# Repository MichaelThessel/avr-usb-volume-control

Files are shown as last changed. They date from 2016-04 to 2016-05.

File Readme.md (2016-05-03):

### USB Volume Control ###

Firmware for USB volume control board

This is project utilizes the [VUSB library](https://github.com/MichaelThessel/avr-usb-volume-control) by Objective Development. A detailed description of the project can be found [here](http://michaelthessel.com/usb-volume-control/). The KiCad design files are located in the PCB folder.

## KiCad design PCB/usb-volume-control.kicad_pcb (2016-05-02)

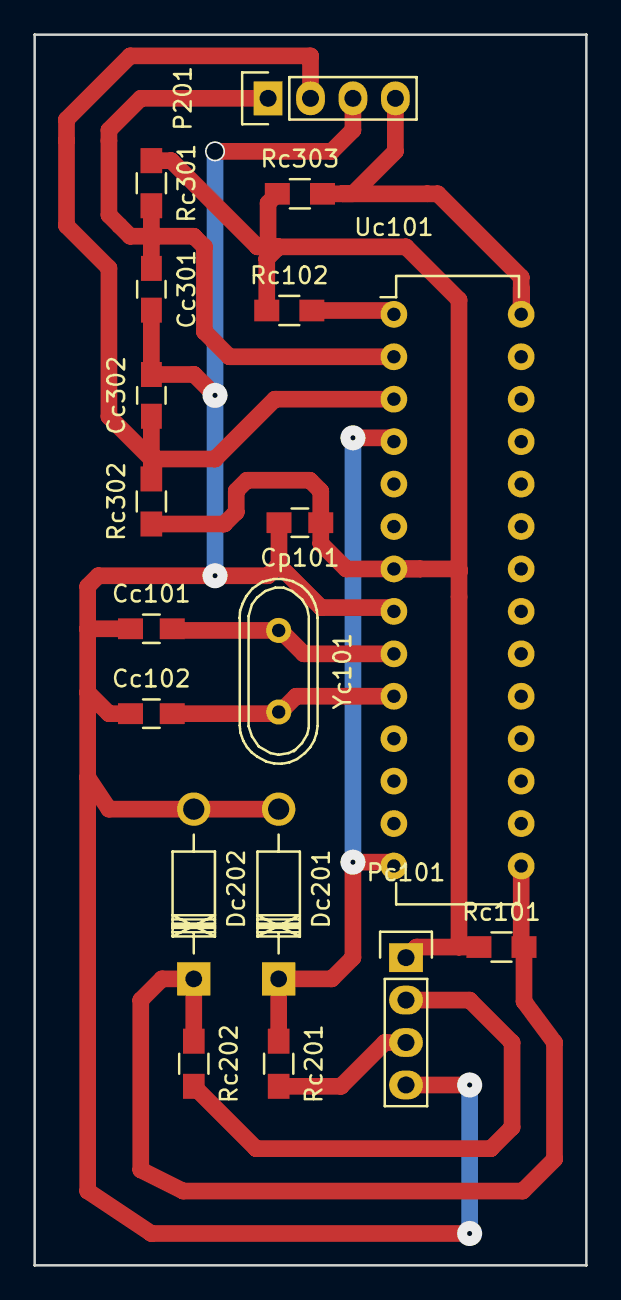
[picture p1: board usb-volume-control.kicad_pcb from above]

Board: 2 copper layers, 33.0 x 73.7 mm, 18 parts (0 on the bottom side), 12 nets.

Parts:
Cc101, Cc102: 22pF; C_0805_HandSoldering
Cc301, Cc302: 1uF; C_0805_HandSoldering
Cp101: 10uF; C_0805_HandSoldering
Dc201, Dc202: 3V6; Diode_DO-41_SOD81_Horizontal_RM10
P201: ROT ENC; Pin_Header_Straight_1x04
Pc101: USB; Pin_Header_Straight_1x04
Rc101, Rc102, Rc301, Rc302, Rc303: 2k; R_0805_HandSoldering
Rc201, Rc202: 47R; R_0805_HandSoldering
Uc101: ATMEGA328P-P; DIP-28_W7.62mm
Yc101: Crystal; Crystal_HC49-U_Vertical

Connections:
GND: Cc101.1, Cc102.1, Cc301.2, Cc302.2, Cp101.2, Dc201.2, Dc202.2, P201.3, Pc101.4, Uc101.8
unnamed: Cc101.2, Uc101.9, Yc101.1
unnamed: Cc102.2, Uc101.10, Yc101.2
unnamed: Cc301.1, P201.1, Rc301.2, Uc101.2
unnamed: Cc302.1, P201.2, Rc302.2, Uc101.3
unnamed: Dc201.1, Rc201.1, Uc101.4, Uc101.14
unnamed: Dc202.1, Rc101.2, Rc202.1, Uc101.15
unnamed: P201.4, Rc303.2, Uc101.28
unnamed: Pc101.2, Rc202.2
unnamed: Pc101.3, Rc201.2
unnamed: Rc102.2, Uc101.1
VCC: Cp101.1, Pc101.1, Rc101.1, Rc102.1, Rc301.1, Rc302.1, Rc303.1, Uc101.7

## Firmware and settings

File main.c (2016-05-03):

#include <avr/io.h>
#include <avr/wdt.h>
#include <avr/interrupt.h>
#include <util/delay.h>
#include <avr/pgmspace.h>

#include "usbdrv/usbdrv.h"

#define STATUS_IDLE 0
#define STATUS_STOP 1
#define STATUS_UP 2
#define STATUS_DOWN 3
#define STATUS_MUTE 4

#define REPID_MMKEY 3

volatile int status = 0;

static uint8_t reportBuffer[3];
static uchar idleRate;

volatile short debounceActive = 0;

const PROGMEM char usbHidReportDescriptor[USB_CFG_HID_REPORT_DESCRIPTOR_LENGTH] = {
    0x05, 0x0C, // USAGE_PAGE (Consumer Devices)
    0x09, 0x01, // USAGE (Consumer Control)
    0xA1, 0x01, // COLLECTION (Application)
    0x85, REPID_MMKEY, // REPORT_ID
    0x19, 0x00, // USAGE_MINIMUM (Unassigned)
    0x2A, 0x3C, 0x02, // USAGE_MAXIMUM
    0x15, 0x00, // LOGICAL_MINIMUM (0)
    0x26, 0x3C, 0x02, // LOGICAL_MAXIMUM
    0x95, 0x01, // REPORT_COUNT (1)
    0x75, 0x10, // REPORT_SIZE (16)
    0x81, 0x00, // INPUT (Data,Ary,Abs)
    0xC0 // END_COLLECTION
}; // Length 25

void buildReport(uint8_t keyCode, uint8_t reportId)
{
    reportBuffer[0] = reportId;
    reportBuffer[1] = keyCode;
    reportBuffer[2] = 0;
}

usbMsgLen_t usbFunctionSetup(uchar data[8])
{
    usbRequest_t *rq = (void *)data;

    if ((rq->bmRequestType & USBRQ_TYPE_MASK) == USBRQ_TYPE_CLASS) {
        if (rq->bRequest == USBRQ_HID_GET_REPORT) {
            usbMsgPtr = (void *)&reportBuffer;
            buildReport(0, 0);
            return sizeof(reportBuffer);
        } else if (rq->bRequest == USBRQ_HID_GET_IDLE) {
            usbMsgPtr = &idleRate;
            return 1;
        } else if (rq->bRequest == USBRQ_HID_SET_IDLE) {
            idleRate = rq->wValue.bytes[1];
        }
    }

    return 0;
}

int main(void)
{

    PORTC &= !((1 << PORTC3) | (1 << PORTC5));

    DDRD &= ~(1 << DDD0) | ~(1 << DDD1); // PD0 & PD1 input
    DDRC &= !(1 << DDC5); // PC5 input
    PCICR |= (1 << PCIE2) | (1 << PCIE1); // Enable pin change interrupts for PCINT[23:16] && [14:8]
    PCMSK2 |= (1 << PCINT16); // Enable pin change interrupt for PCINT16
    PCMSK1 |= (1 << PCINT13); // Enable pin change interrupt for PCINT13
    EICRA |= (1 << ISC11); // Trigger pin change interrupt on falling edge

    wdt_enable(WDTO_1S);

    usbInit();
    usbDeviceDisconnect();

    uint8_t i = 0;
    while(--i) {
        wdt_reset();
        _delay_ms(1);
    }

    usbDeviceConnect();

    sei();

    while(1) {
        wdt_reset();
        usbPoll();

        // Process key presses
        if (status != STATUS_IDLE && usbInterruptIsReady()) {

            switch (status) {
                case STATUS_UP:
                    buildReport(0xE9, REPID_MMKEY);
                    status = STATUS_STOP;
                    break;

                case STATUS_DOWN:
                    buildReport(0xEA, REPID_MMKEY);
                    status = STATUS_STOP;
                    break;

                case STATUS_MUTE:
                    buildReport(0xE2, REPID_MMKEY);
                    status = STATUS_STOP;
                    break;

                case STATUS_STOP:
                    buildReport(0, 0);
                    status = STATUS_IDLE;
                    break;
            }

            sei();

            usbSetInterrupt((void *)&reportBuffer, sizeof(reportBuffer));
        }
    }


    return 0;
}

// Enable debounce
void debounce()
{
    debounceActive = 1;
    TCCR0B |= (1 << CS00) | (1 << CS01); // prescaler 1024
 TIMSK0 |= (1 << OCIE0A); // Enable timer compare match interrupt
}

// Handle rotary encoder spin
ISR(PCINT2_vect)
{
    if (debounceActive) return;

    // Falling edge on PIND0
    if (!(PIND & (1 << PIND1))) {

        cli();
        debounce();

        if (PIND & (1 << PIND0)) {
            // PIND1 high -> right turn
            status = STATUS_DOWN;
        } else {
            // PIND1 high -> left turn
            status = STATUS_UP;
        }
    }
}

// Handle rotary encoder button push
ISR(PCINT1_vect)
{
    if (debounceActive) return;

    cli();
    if (PINC & (1 << PIND5)) {
        status = STATUS_MUTE;
        debounce();
    }
}

// Disable debounce
ISR(TIMER0_COMPA_vect)
{
    debounceActive = 0;
    TIMSK0 &= ~(1 << OCIE0A);
}

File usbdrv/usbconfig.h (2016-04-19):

/* Name: usbconfig.h
 * Project: V-USB, virtual USB port for Atmel's(r) AVR(r) microcontrollers
 * Author: Christian Starkjohann
 * Creation Date: 2005-04-01
 * Tabsize: 4
 * Copyright: (c) 2005 by OBJECTIVE DEVELOPMENT Software GmbH
 * License: GNU GPL v2 (see License.txt), GNU GPL v3 or proprietary (CommercialLicense.txt)
 */

#ifndef __usbconfig_h_included__
#define __usbconfig_h_included__

/*
General Description:
This file is an example configuration (with inline documentation) for the USB
driver. It configures V-USB for USB D+ connected to Port D bit 2 (which is
also hardware interrupt 0 on many devices) and USB D- to Port D bit 4. You may
wire the lines to any other port, as long as D+ is also wired to INT0 (or any
other hardware interrupt, as long as it is the highest level interrupt, see
section at the end of this file).
+ To create your own usbconfig.h file, copy this file to your project's
+ firmware source directory) and rename it to "usbconfig.h".
+ Then edit it accordingly.
*/

/* ---------------------------- Hardware Config ---------------------------- */

#define USB_CFG_IOPORTNAME      B
/* This is the port where the USB bus is connected. When you configure it to
 * "B", the registers PORTB, PINB and DDRB will be used.
 */
#define USB_CFG_DMINUS_BIT      1
/* This is the bit number in USB_CFG_IOPORT where the USB D- line is connected.
 * This may be any bit in the port.
 */
#define USB_CFG_DPLUS_BIT       0
/* This is the bit number in USB_CFG_IOPORT where the USB D+ line is connected.
 * This may be any bit in the port. Please note that D+ must also be connected
 * to interrupt pin INT0! [You can also use other interrupts, see section
 * "Optional MCU Description" below, or you can connect D- to the interrupt, as
 * it is required if you use the USB_COUNT_SOF feature. If you use D- for the
 * interrupt, the USB interrupt will also be triggered at Start-Of-Frame
 * markers every millisecond.]
 */
#define USB_CFG_CLOCK_KHZ       12000
/* Clock rate of the AVR in kHz. Legal values are 12000, 12800, 15000, 16000,
 * 16500, 18000 and 20000. The 12.8 MHz and 16.5 MHz versions of the code
 * require no crystal, they tolerate +/- 1% deviation from the nominal
 * frequency. All other rates require a precision of 2000 ppm and thus a
 * crystal!
 * Since F_CPU should be defined to your actual clock rate anyway, you should
 * not need to modify this setting.
 */
#define USB_CFG_CHECK_CRC       0
/* Define this to 1 if you want that the driver checks integrity of incoming
 * data packets (CRC checks). CRC checks cost quite a bit of code size and are
 * currently only available for 18 MHz crystal clock. You must choose
 * USB_CFG_CLOCK_KHZ = 18000 if you enable this option.
 */

/* ----------------------- Optional Hardware Config ------------------------ */

/* #define USB_CFG_PULLUP_IOPORTNAME   D */
/* If you connect the 1.5k pullup resistor from D- to a port pin instead of
 * V+, you can connect and disconnect the device from firmware by calling
 * the macros usbDeviceConnect() and usbDeviceDisconnect() (see usbdrv.h).
 * This constant defines the port on which the pullup resistor is connected.
 */
/* #define USB_CFG_PULLUP_BIT          4 */
/* This constant defines the bit number in USB_CFG_PULLUP_IOPORT (defined
 * above) where the 1.5k pullup resistor is connected. See description
 * above for details.
 */

/* --------------------------- Functional Range ---------------------------- */
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

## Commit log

2016-04-20 Added PCB layout
    [usb-volume-control.kicad_pcb, usb-volume-control.sch]
2016-04-21 Improved PCB layout
    [usb-volume-control.kicad_pcb, usb-volume-control.sch]
2016-04-30 Fixed connection error
    [usb-volume-control.kicad_pcb, usb-volume-control.sch]
2016-05-02 Changed rotary encoder capacitor value
    [usb-volume-control.kicad_pcb, usb-volume-control.sch]
2016-05-02 Added support for rotary encoder push button
2016-05-03 Switched to timers for debouncing
